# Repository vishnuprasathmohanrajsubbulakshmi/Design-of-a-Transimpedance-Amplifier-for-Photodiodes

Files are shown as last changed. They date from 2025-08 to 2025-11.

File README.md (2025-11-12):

# Design of a Transimpedance Amplifier (TIA) for Photodiodes

## Overview
This project presents the **design, simulation, and PCB layout** of a high-sensitivity Transimpedance Amplifier (TIA) optimized for use with photodiodes.  
Two photodiode models were evaluated: **BPW 21** and **SFH 229**, with a focus on DC performance, frequency response, and noise characteristics.

---

## Objective
The primary goal was to design a low-noise, high-gain transimpedance amplifier capable of accurately converting photodiode current into a measurable voltage signal, suitable for optical sensing applications.

---

## Photodiodes Used
- **BPW 21** – High responsivity photodiode
- **SFH 229** – Silicon photodiode with low capacitance

---

## Circuit Design
- **Topology:** Op-amp based TIA
- **Feedback Resistors:** Tested at **5 MΩ** and **50 MΩ**
- **Simulation Tools:** Pspice and AutoDesk Eagle
- **PCB Layout:** Designed for low parasitics and minimal noise pickup

---

## Simulation & Analysis Results

### DC Sweep
- BPW 21 and SFH 229 tested with **R1 = 5 MΩ**
- Output voltage shows expected linear relationship with photodiode current

### AC Sweep (Frequency Response)
- Frequency response measured for both photodiodes
- Performance optimized for target bandwidth

### Noise Analysis
- **Integrated Noise:**
  - BPW 21: 36.6 µV
  - SFH 229: 4.1 µV
- **Peak-to-Peak Noise (50 MΩ feedback):**
  - BPW 21: 34.54 mV (Effective Noise: 5.76 mV)
  - SFH 229: 7.36 mV (Effective Noise: 1.23 mV)

### Offset Measurements
- BPW 21: −1.228 mV
- SFH 229: −524 µV

---

## PCB Design
- Compact, low-noise PCB layout
- Photodiode mounted close to TIA input to minimize parasitic capacitance
- Ground plane used for shielding

---

## Key Learnings
- Feedback resistor value directly impacts gain and noise
- Photodiode capacitance strongly influences bandwidth
- Layout and grounding are critical for low-noise operation

---

## Future Improvements
- Use of ultra-low bias current op-amps for further noise reduction
- Temperature drift compensation
- Integration with ADC for digital readout

---

## License

---

## How to Use
1. Clone this repository:
   ```bash
   git clone https://github.com/username/TIA-photodiode.git

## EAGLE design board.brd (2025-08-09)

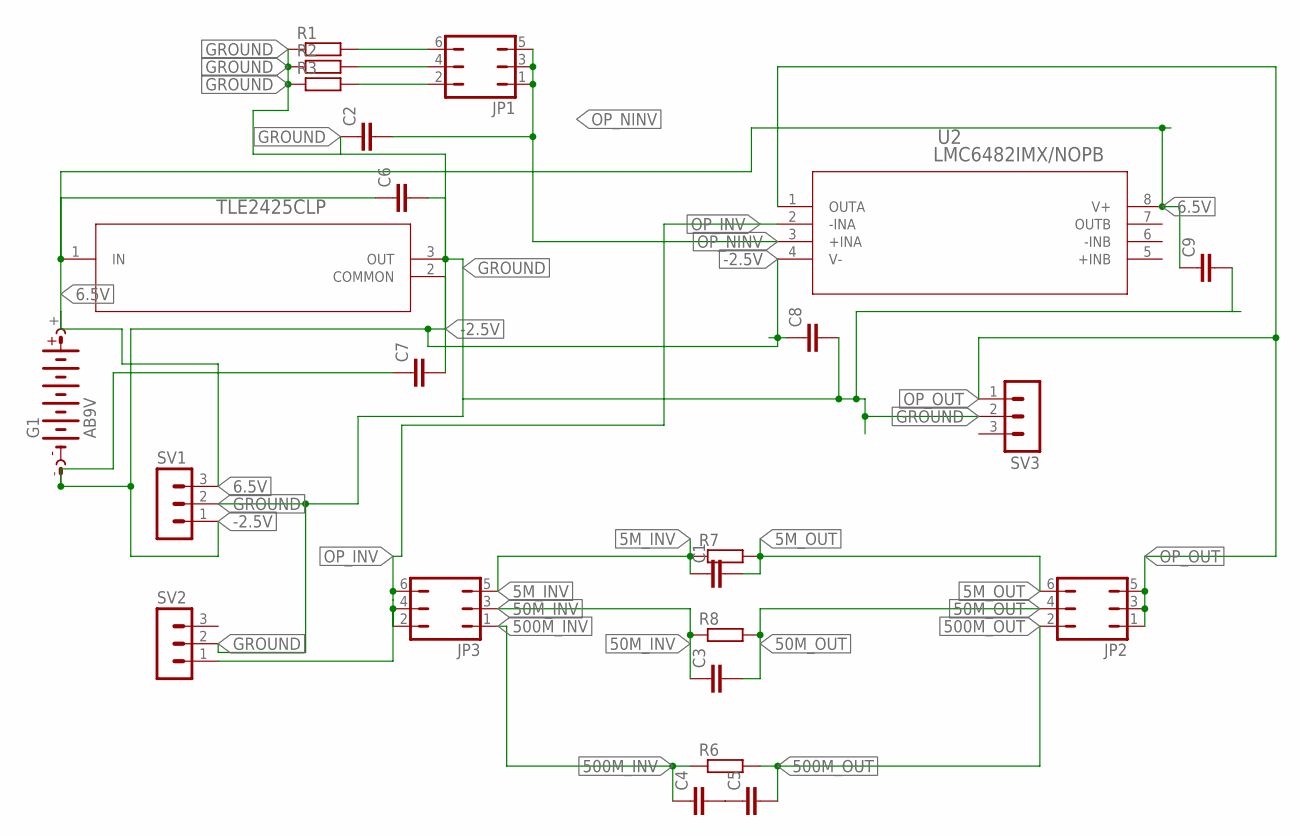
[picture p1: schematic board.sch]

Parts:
C1, C6, C7, C8, C9: C-EUC0402; C0402
C2, C5: C-EUC0805; C0805
C3, C4: C-EUC0603; C0603
G1: AB9V
JP1, JP2, JP3: JP3Q
R1, R6: R-EU_R2010; R2010
R2, R8: R-EU_R1206; R1206
R3, R7: R-EU_R2512; R2512
SV1, SV2, SV3: MA03-1
U1: TLE2425CLP; LP3
U2: LMC6482IMX/NOPB; M08A

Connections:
5M_INV: C1.1, JP3.5, R7.1
5M_OUT: C1.2, JP2.6, R7.2
6.5V: C6.1, C9.1, G1.+, SV1.3, U1.1 (IN), U2.8 (V+)
50M_INV: C3.1, JP3.3, R8.1
50M_OUT: C3.2, JP2.4, R8.2
500M_INV: C4.1, JP3.1, R6.1
500M_OUT: C5.2, JP2.2, R6.2
-2.5V: C7.1, C8.1, G1.-, SV1.1, U1.2 (COMMON), U2.4 (V-)
GROUND: C2.1, C6.2, C7.2, C8.2, C9.2, R1.1, R2.1, R3.1, SV1.2, SV2.2, SV3.2, U1.3 (OUT)
unnamed: C4.2, C5.1
unnamed: JP1.2, R3.2
unnamed: JP1.4, R2.2
unnamed: JP1.6, R1.2
OP_INV: JP3.2, JP3.4, JP3.6, SV2.1, U2.2 (-INA)
OP_NINV: C2.2, JP1.1, JP1.3, JP1.5, U2.3 (+INA)
OP_OUT: JP2.1, JP2.3, JP2.5, SV3.1, U2.1 (OUTA)

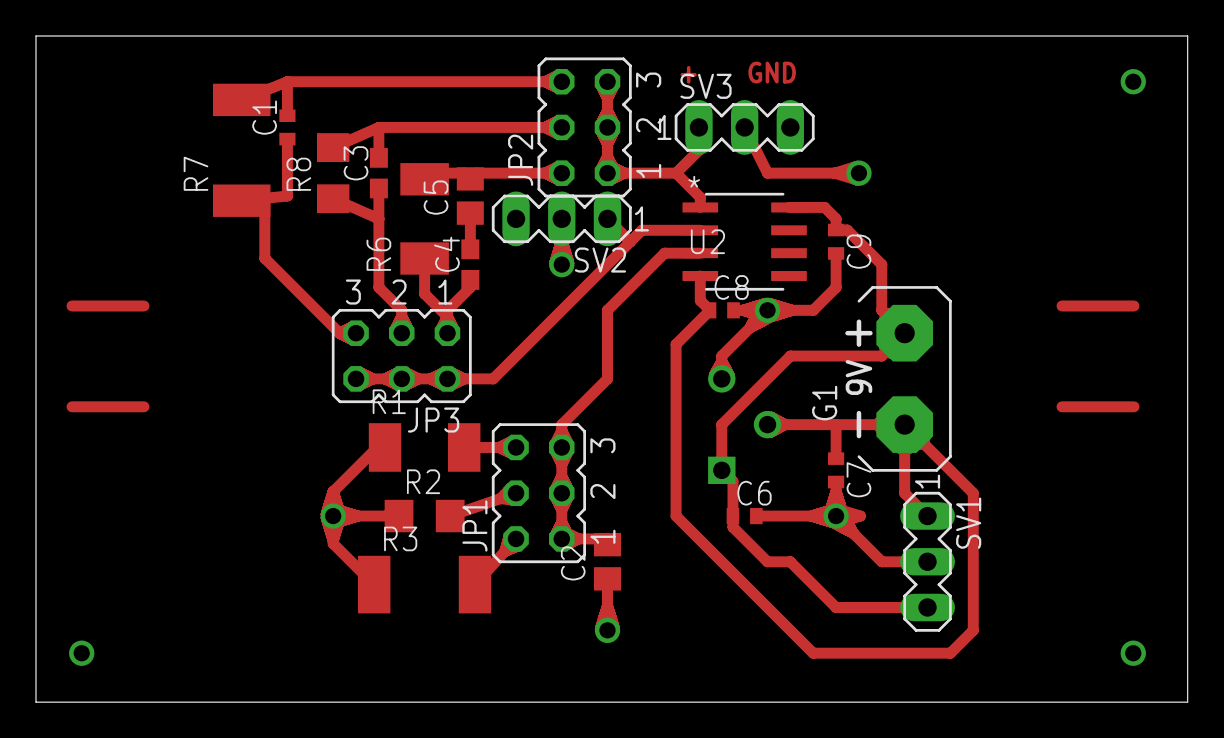
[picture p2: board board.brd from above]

Board: 2 copper layers, 64.0 x 37.0 mm, 24 parts (1 on the bottom side), 16 nets.
